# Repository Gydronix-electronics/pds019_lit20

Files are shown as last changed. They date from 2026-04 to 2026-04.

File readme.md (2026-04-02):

# PDS019_lit20

В этом репозитории содержатся исходники устройства PDS019_lit20.

Конструктивно устройство представляет из себя две печатные платы, размещенные в корпусе для монтажа на DIN-рейку [GAINTA D3MG](https://www.gainta.com/en/d3mg.html)

<p align = center>
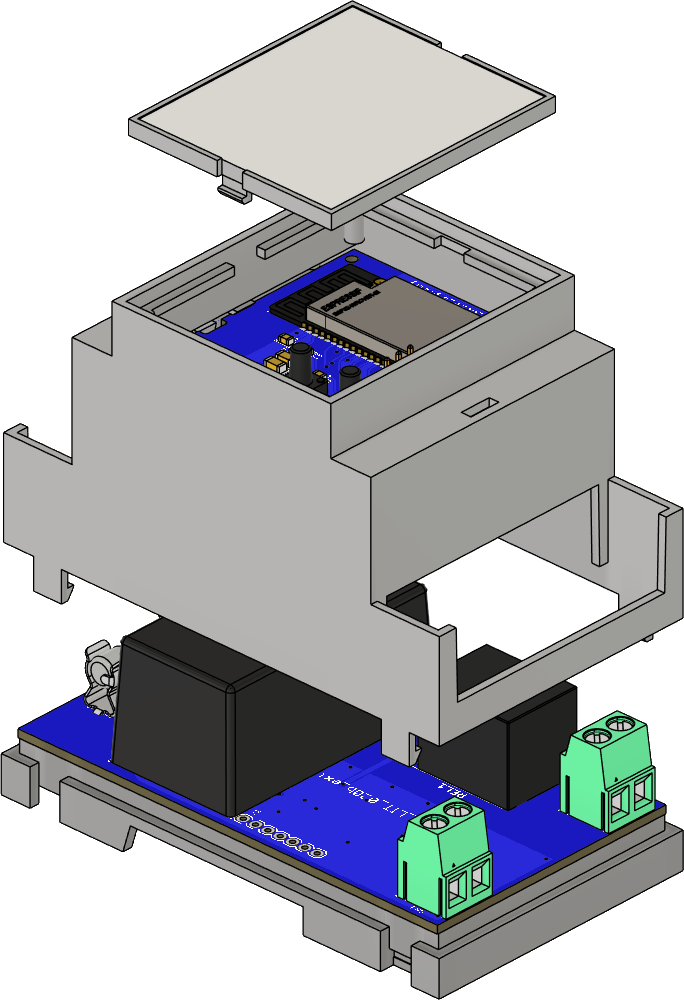
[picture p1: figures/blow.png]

</p>

# Внешний вид платы А (верхней платы)

<p align = center>
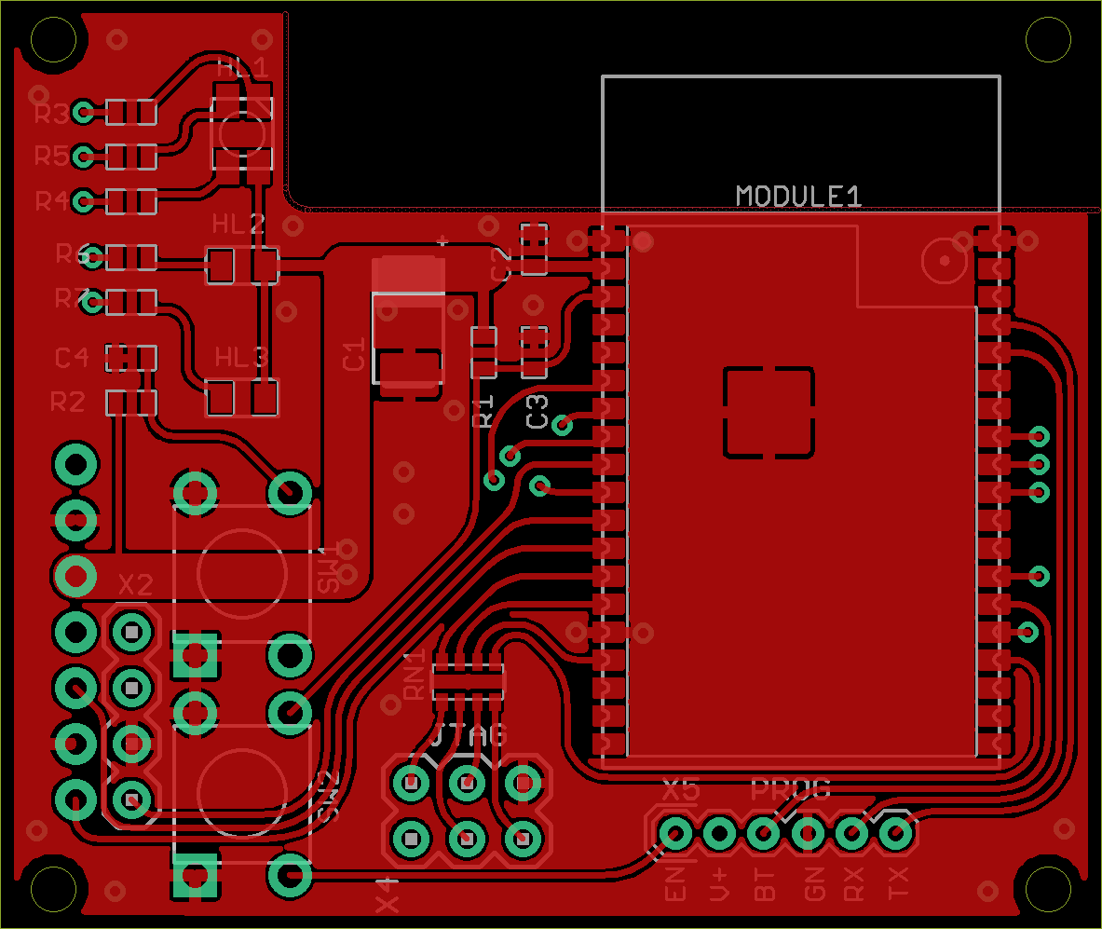
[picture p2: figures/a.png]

</p>

# Внешний вид платы B (нижней платы)

<p align = center>
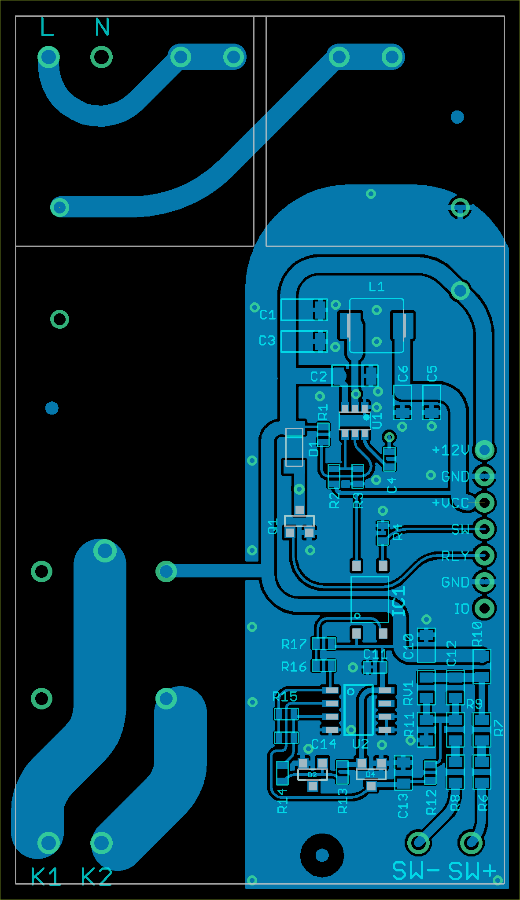
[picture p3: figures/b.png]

</p>

3d модель для онлайн просмотра доступна [по ссылке](https://a360.co/4tmWj8G)

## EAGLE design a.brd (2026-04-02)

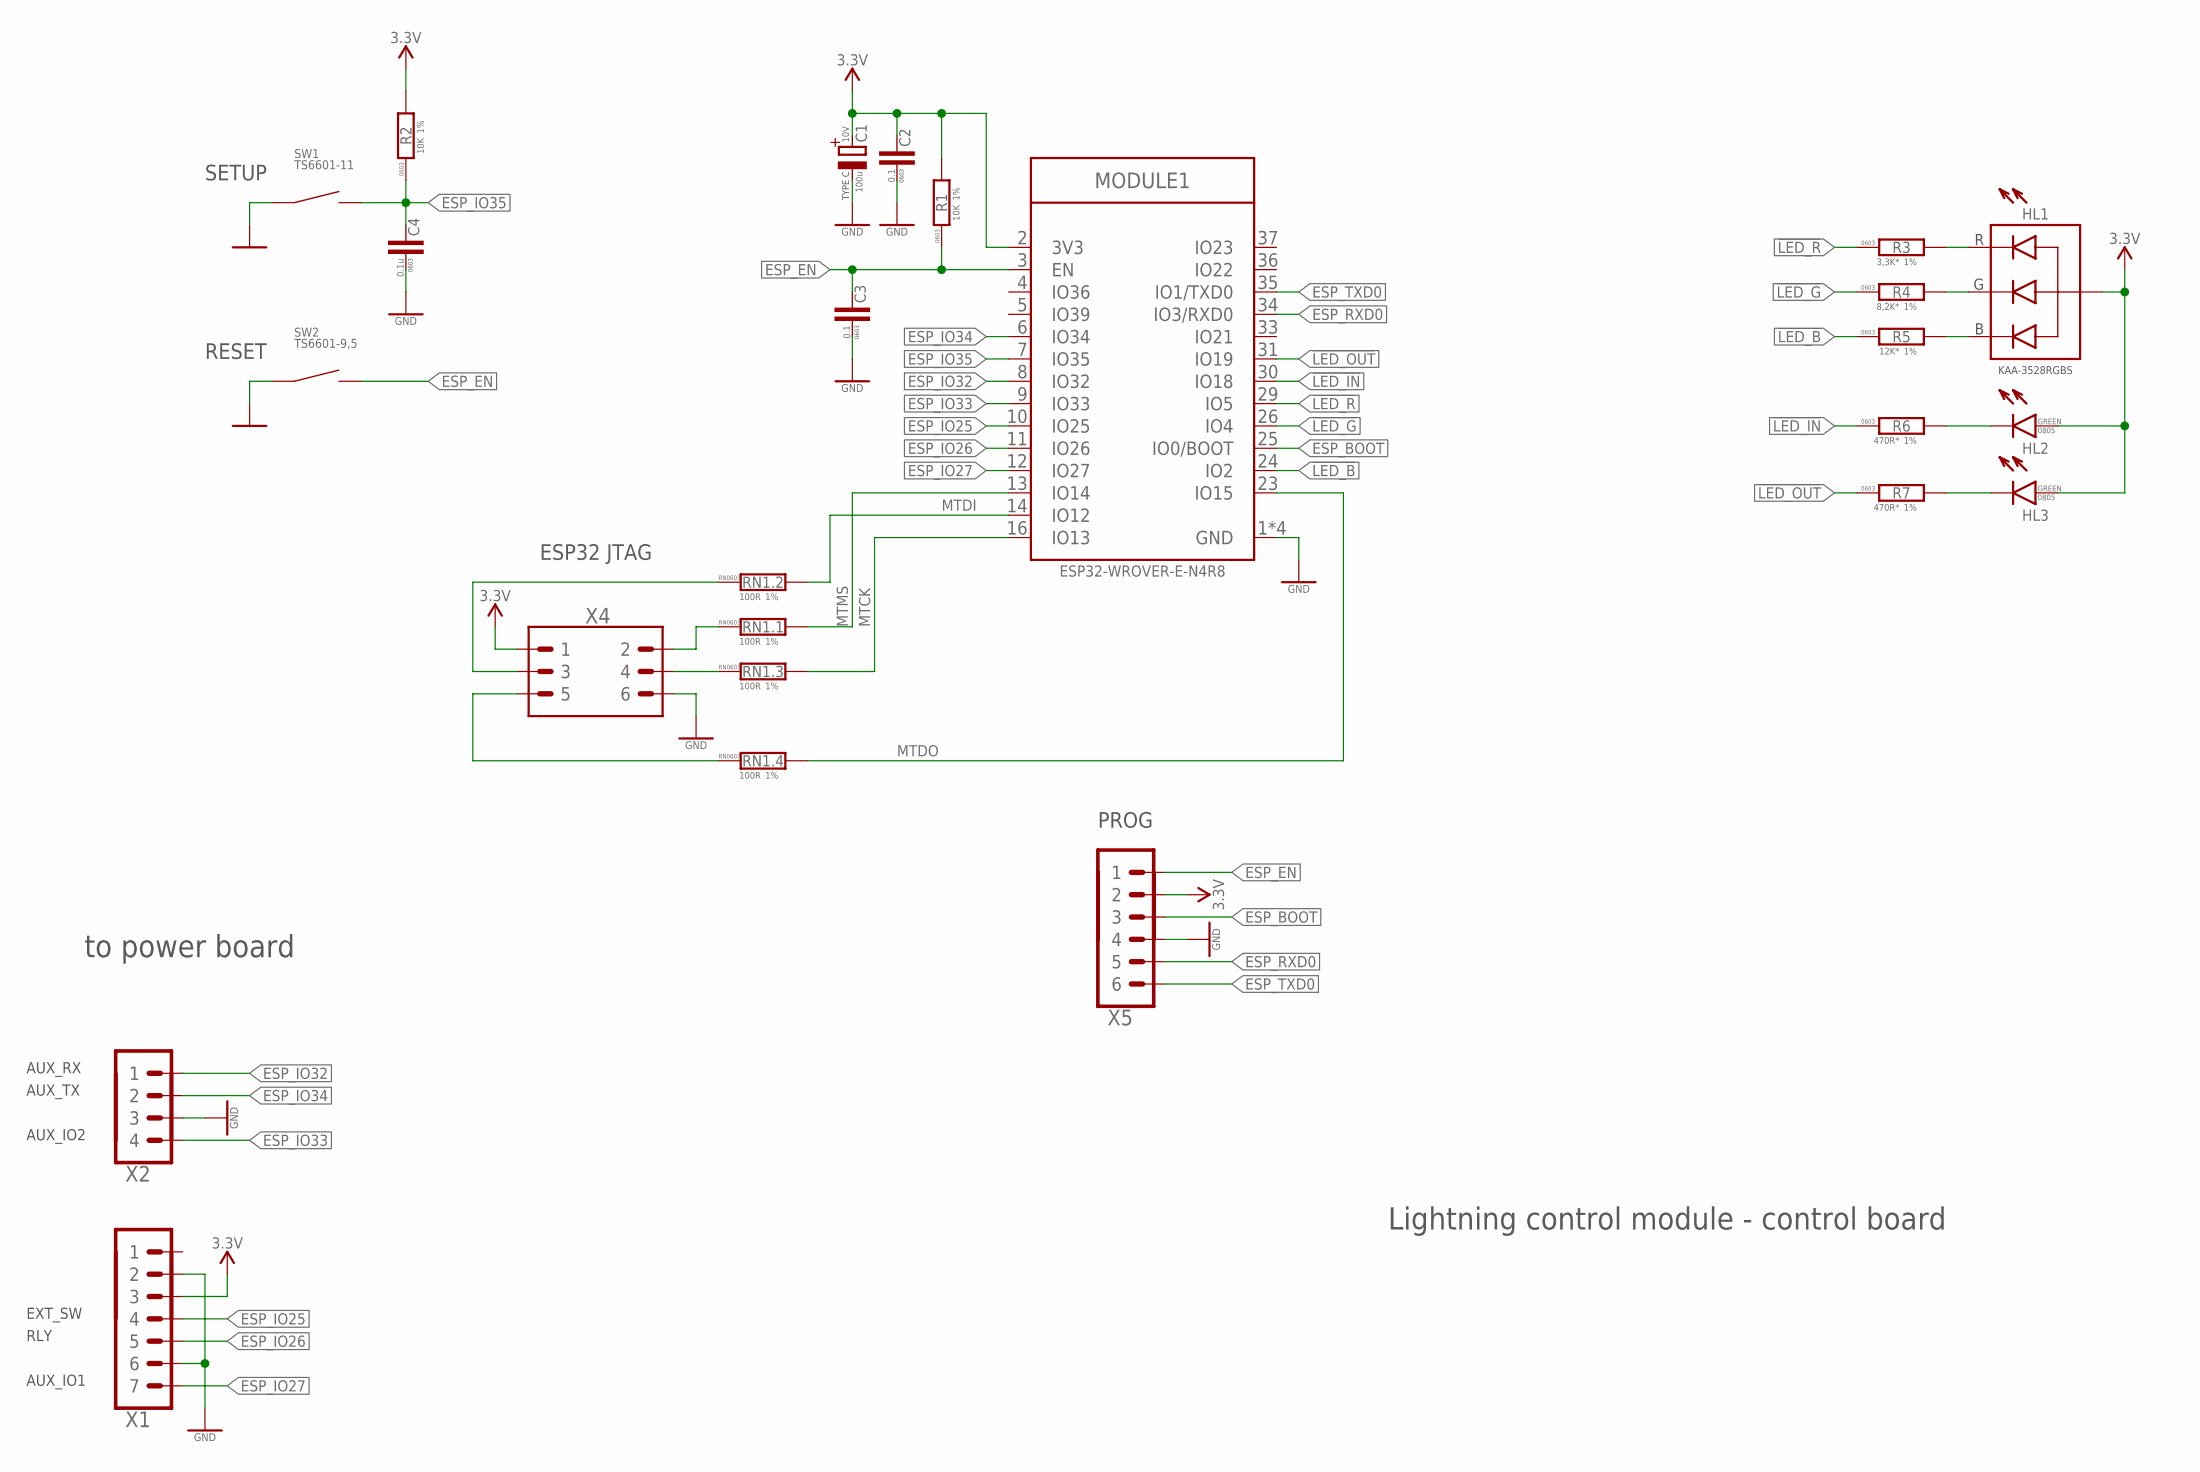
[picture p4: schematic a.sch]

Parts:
C1: 100u; CTANT_TYPE_C; VOLTAGE 10V
C2, C3: 0.1; C0603
C4: 0.1u; C0603
HL1: LED_RGB-KAA-3528RGBS; LED3528
HL2, HL3: LED-0805; LED0805
MODULE1: ESP32-WROVER-(I)E; ESP32-WROVER-E
R1, R2: 10K; R0603
R3: 3,3K*; R0603
R4: 8,2K*; R0603
R5: 12K*; R0603
R6, R7: 470R*; R0603
RN1: 100R; R_4X0603
SW1: TS6601-11; SW4-6.0X6.0X5.0MM
SW2: TS6601-9,5; SW4-6.0X6.0X5.0MM
X1: PINHEAD_1X07-2.54; 1X07-PTH-2.54
X2: PINHEAD_1X04-2.54; 1X04-PTH-2.54
X4: PINHEAD_2X03-PTH-2.54; 2X03-PTH-2.54
X5: PINHEAD_1X06-2-MALE; 1X06-PTH-2

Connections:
!LED_B: MODULE1.24 (IO2), R5.1
!LED_G: MODULE1.26 (IO4), R4.1
!LED_IN: MODULE1.30 (IO18), R6.1
!LED_OUT: MODULE1.31 (IO19), R7.1
!LED_R: MODULE1.29 (IO5), R3.1
ESP_BOOT: MODULE1.25 (IO0/BOOT), X5.3
ESP_EN: C3.2, MODULE1.3 (EN), R1.1, SW2.2, SW2.3 (2), X5.1
ESP_IO25: MODULE1.10 (IO25), X1.4
ESP_IO26: MODULE1.11 (IO26), X1.5
ESP_IO27: MODULE1.12 (IO27), X1.7
ESP_IO32: MODULE1.8 (IO32), X2.1
ESP_IO33: MODULE1.9 (IO33), X2.4
ESP_IO34: MODULE1.6 (IO34), X2.2
ESP_IO35: C4.2, MODULE1.7 (IO35), R2.1, SW1.2, SW1.3 (2)
ESP_RXD0: MODULE1.34 (IO3/RXD0), X5.5
ESP_TXD0: MODULE1.35 (IO1/TXD0), X5.6
GND: C1.-, C2.1, C3.1, C4.1, MODULE1.1 (GND), MODULE1.15 (GND), MODULE1.38 (GND), MODULE1.39 (GND), SW1.1, SW1.4 (1), SW2.1, SW2.4 (1), X1.2, X1.6, X2.3, X4.6, X5.4
MTCK: MODULE1.16 (IO13), RN1.6 (2)
MTDI: MODULE1.14 (IO12), RN1.7 (2)
MTDO: MODULE1.23 (IO15), RN1.5 (2)
MTMS: MODULE1.13 (IO14), RN1.8 (2)
unnamed: HL1.4 (B), R5.2
unnamed: HL1.3 (G), R4.2
unnamed: HL1.1 (R), R3.2
unnamed: HL2.C, R6.2
unnamed: HL3.C, R7.2
unnamed: RN1.4 (1), X4.5
unnamed: RN1.1, X4.2
unnamed: RN1.2 (1), X4.3
unnamed: RN1.3 (1), X4.4
VDD_3V3: C1.+, C2.2, HL1.2 (A), HL2.A, HL3.A, MODULE1.2 (3V3), R1.2, R2.2, X1.3, X4.1, X5.2

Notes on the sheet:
ESP32 JTAG
RESET
SETUP
PROG
to power board
AUX_RX
AUX_TX
AUX_IO2
EXT_SW
RLY
AUX_IO1
Lightning control module - control board

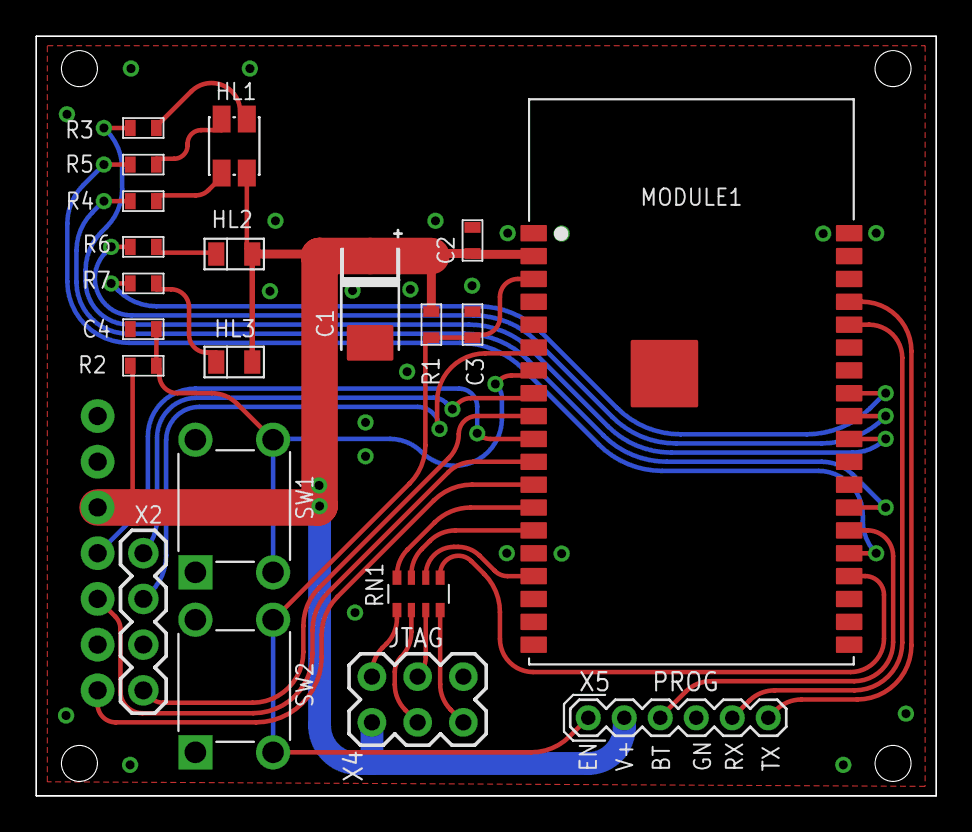
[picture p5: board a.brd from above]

Board: 2 copper layers, 50.0 x 42.2 mm, 23 parts (1 on the bottom side), 31 nets.

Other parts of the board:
U$2: D3MG_PCB_UP

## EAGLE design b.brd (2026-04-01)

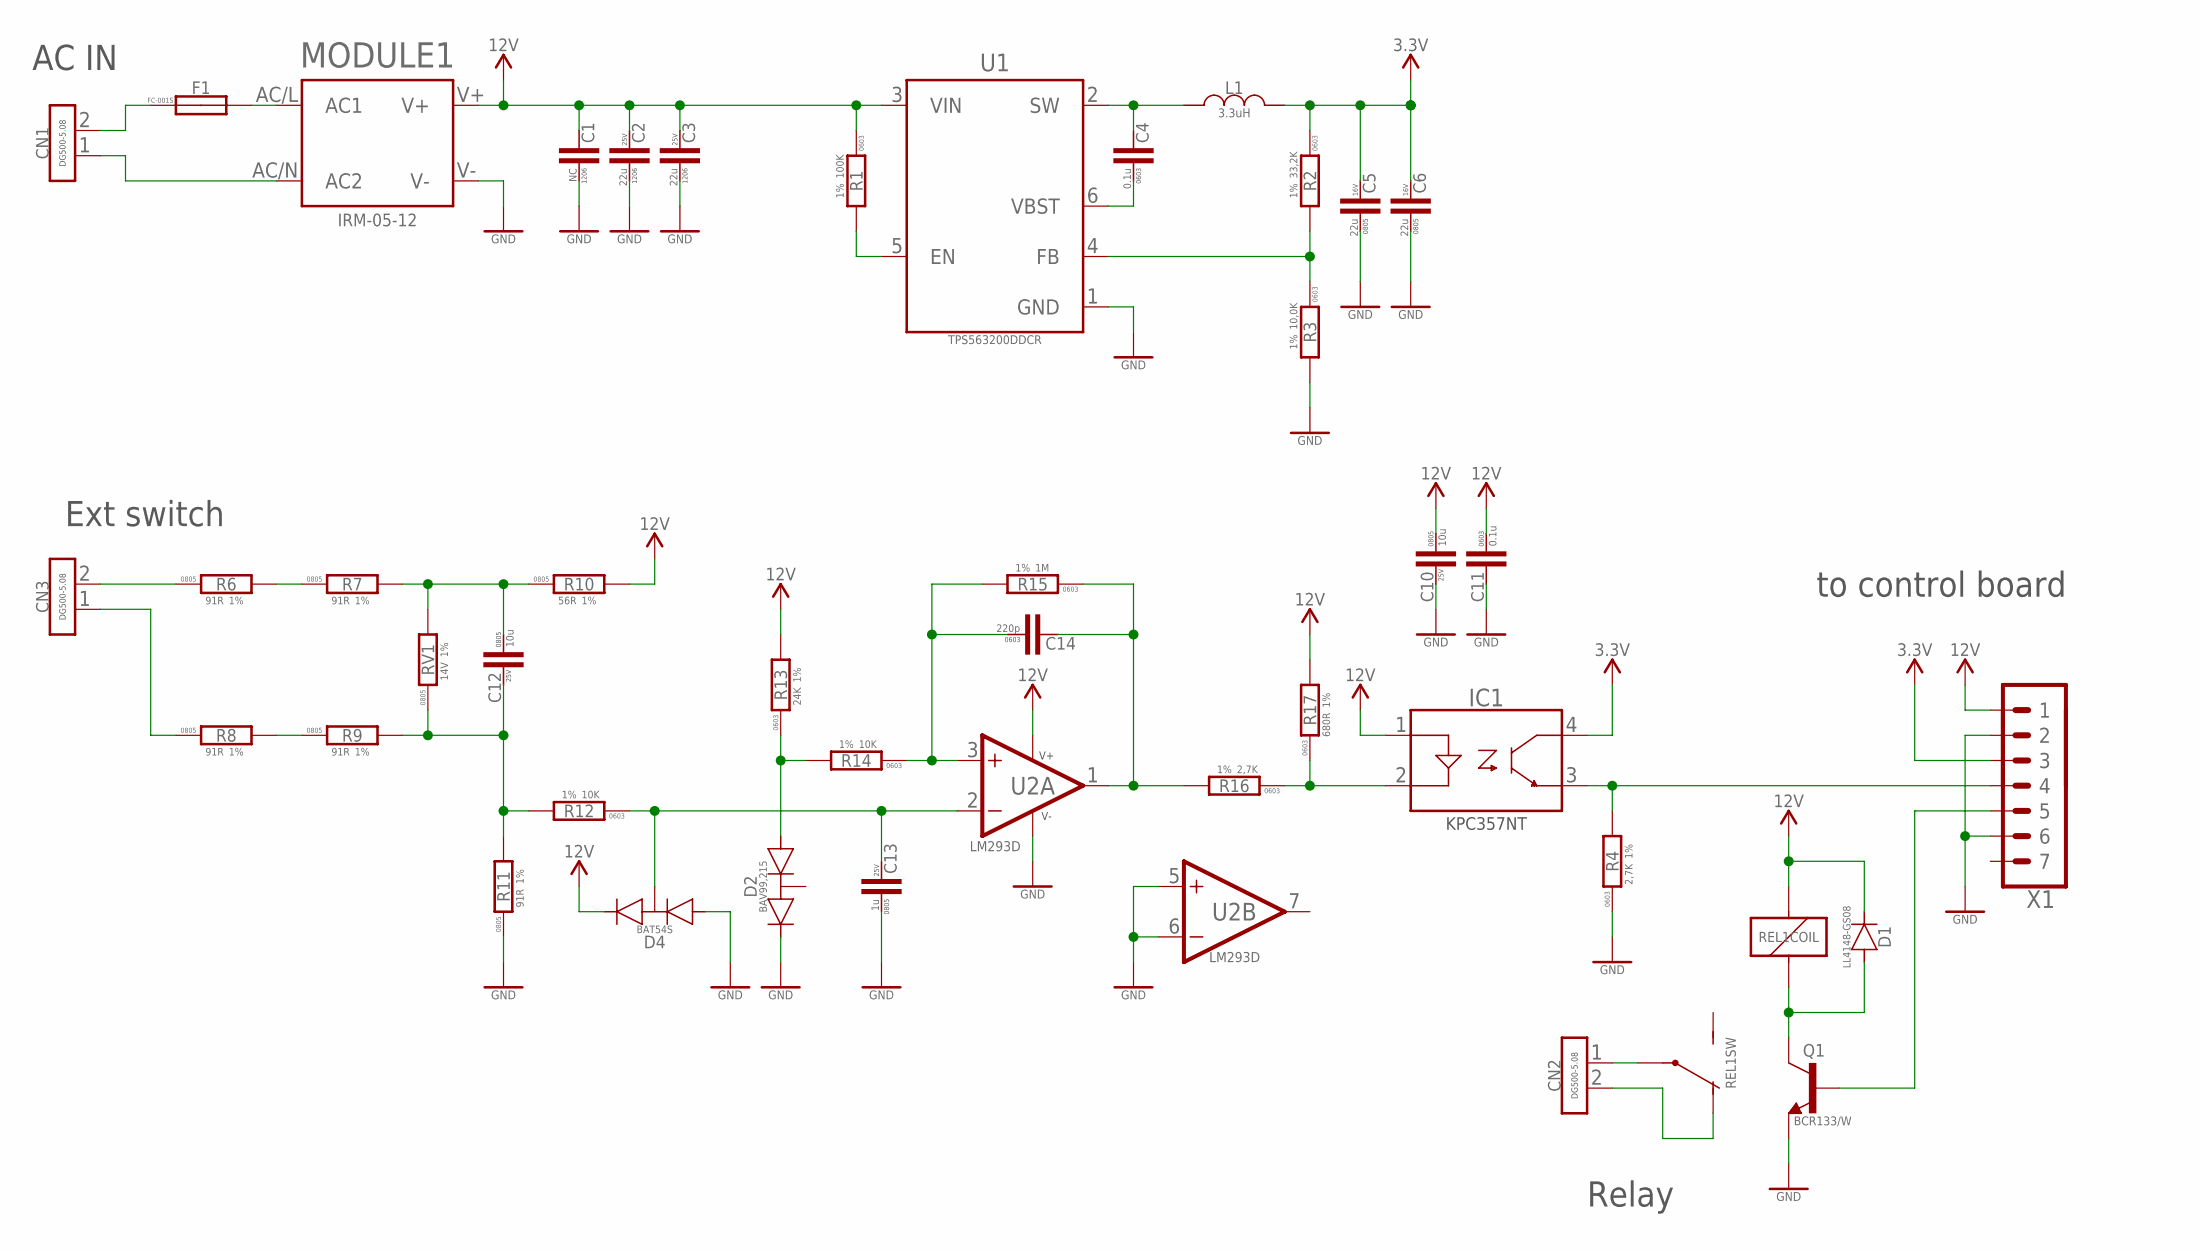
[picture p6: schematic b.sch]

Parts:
C1: NC; C1206
C2, C3: 22u; C1206; VOLTAGE 25V
C4, C11: 0.1u; C0603
C5, C6: 22u; C0805; VOLTAGE 16V
C10, C12: 10u; C0805; VOLTAGE 25V
C13: 1u; C0805; VOLTAGE 25V
C14: 220p; C0603
CN1, CN3: DG508V-2P; DG500-5.08-02P
CN2: CON-2P-DG500-5.08; DG500-5.08-02P
D1: LL4148; LL-34
D2: BAV99-SOT23; SOT23
D4: BAT54S-SOT23; SOT23
F1: 2A; FC-001S
IC1: KPC357NT-SOP-4; -SOP-4
L1: 3.3uH; LSMD_05020
MODULE1: IRM-05-12; IRM-05
Q1: BCR133; SOT23B-3
R1: 100K; R0603
R2: 33,2K; R0603
R3: 10,0K; R0603
R4, R16: 2,7K; R0603
R6, R7, R8, R9, R11: 91R; R0805
R10: 56R; R0805
R12, R14: 10K; R0603
R13: 24K; R0603
R15: 1M; R0603
R17: 680R; R0603
REL1: RELAY_SPDTHJR-3FF-SH; HJR-3FF-12VDC-S-Z
RV1: 14V; R0805
U1: TPS563200; SOT23-6
U2: LM293D; SOIC8
X1: PINHEAD_1X07-2.54; 1X07-PTH-2.54

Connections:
EXT_SW: IC1.3 (EMITTER), R4.2, X1.4
GND: C1.P$1 (1), C2.P$1 (1), C3.P$1 (1), C5.1, C6.1, C10.2, C11.2, C13.1, D2.2 (C), D4.1 (A), MODULE1.V-, Q1.2 (E), R3.2, R4.1, R11.1, U1.1 (GND), U2.4 (V-), U2.5 (IN+), U2.6 (IN-), X1.2, X1.6
unnamed: D1.A, Q1.3 (C), REL1.2 (1)
unnamed: Q1.1 (B), X1.5
unnamed: CN2.1, REL1.1 (COM)
unnamed: CN1.1, MODULE1.AC/N (AC2)
unnamed: CN1.2, F1.1-1 (1), F1.1-2 (1)
unnamed: F1.2-1 (2), F1.2-2 (2), MODULE1.AC/L (AC1)
unnamed: CN2.2, REL1.4 (NC)
unnamed: R2.2, R3.1, U1.4 (FB)
unnamed: CN3.2, R6.1
unnamed: CN3.1, R8.1
unnamed: R1.2, U1.5 (EN)
unnamed: C4.1, U1.6 (VBST)
unnamed: C4.2, L1.1, U1.2 (SW)
unnamed: IC1.2 (C), R16.1, R17.1
unnamed: C14.2, R15.1, R16.2, U2.1 (OUT)
unnamed: C13.2, D4.3 (COMMON), R12.1, U2.2 (IN-)
unnamed: C12.1, R7.2, R10.1, RV1.2
unnamed: R6.2, R7.1
unnamed: R8.2, R9.1
unnamed: C14.1, R14.1, R15.2, U2.3 (IN+)
unnamed: D2.1 (A), R13.1, R14.2
unnamed: C12.2, R9.2, R11.2, R12.2, RV1.1
VDD_3V3: C5.2, C6.2, IC1.4 (COLLECTOR), L1.2, R2.1, X1.3
VDD_12V: C1.P$2 (2), C2.P$2 (2), C3.P$2 (2), C10.1, C11.1, D1.C, D4.2 (C), IC1.1 (A), MODULE1.V+, R1.1, R10.2, R13.2, R17.2, REL1.5 (2), U1.3 (VIN), U2.8 (V+), X1.1

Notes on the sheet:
Ext switch
AC IN
Relay
to control board

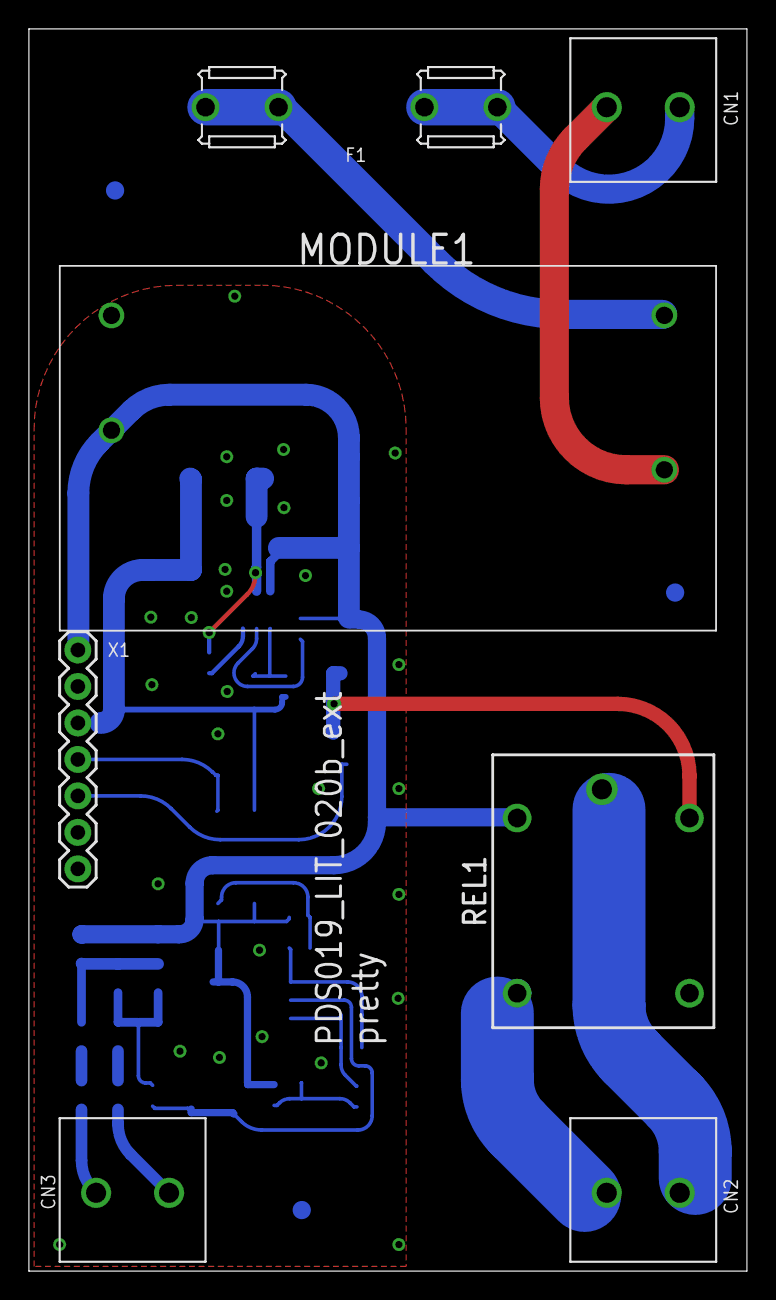
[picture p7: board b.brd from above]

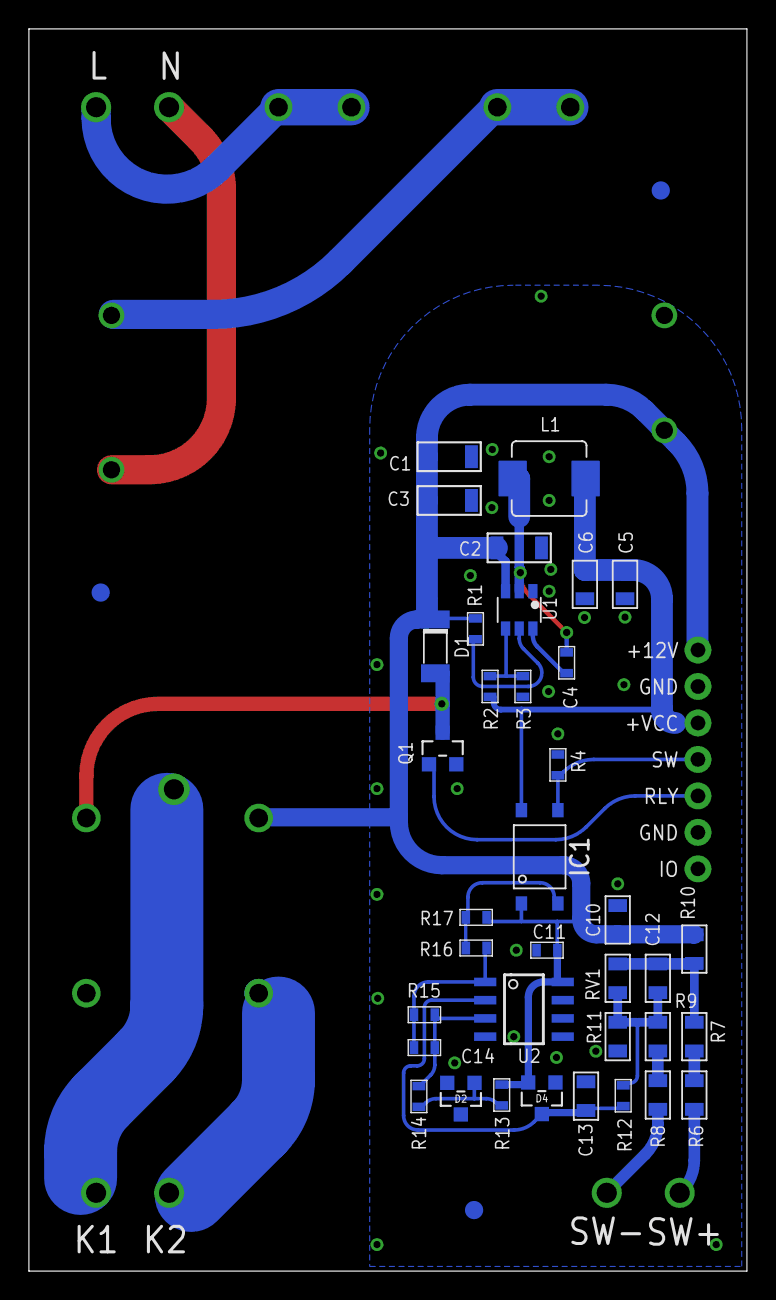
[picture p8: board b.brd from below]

Board: 2 copper layers, 50.0 x 86.5 mm, 47 parts (39 on the bottom side), 26 nets.

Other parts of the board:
PCB_B: D3MG_PCB
U$1, U$2, U$3: REF_POINT_D1.27_D3.81

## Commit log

2026-04-01 initial import
    [a.brd, a.sch, b.brd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]
2026-04-02 A pcb updated
    [a.brd, a.sch]
2026-04-02 Libraries update
    [a.brd, a.sch]
